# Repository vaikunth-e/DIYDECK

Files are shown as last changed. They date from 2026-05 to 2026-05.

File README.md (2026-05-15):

# DIYDECK: STM32 Audio Effects Processor with Custom PCB

DIYDECK is a custom audio-processing board/system that takes an external audio signal, conditions it for an STM32 ADC, applies real-time embedded DSP effects, and outputs the processed signal through the STM32 DAC into the audio board/amplifier path.

[Demo](https://youtu.be/CMMS7bL4tLE)

## Features

- STM32 Nucleo-F303RE firmware using PlatformIO
- Real-time ADC-to-DAC audio passthrough
- Timer-driven sampling using TIM3
- Freeverb-style reverb
- Ring modulation
- Rotary encoder control for PWM-selected filter settings
- Mute switch and button-controlled effects
- Custom KiCad PCB files included

## System overview

Input audio is AC-coupled and biased around mid-supply so the STM32 ADC can sample the waveform safely. The firmware removes the measured DC bias, applies optional effects, recenters the signal around the DAC midpoint, and outputs it through DAC channel 1.

Signal chain:

Laptop / audio source  
→ AC coupling and biasing  
→ STM32 ADC input  
→ real-time DSP  
→ STM32 DAC output  
→ PCB audio path / amplifier / speaker

## Hardware

- STM32 Nucleo-F303RE
- ADC input: A0 / PA0 / ADC1_IN1
- DAC output: A2 / PA4 / DAC_OUT1
- Rotary encoder for filter selection
- Effect buttons for reverb and ring modulation
- Mute switch
- Custom PCB designed in KiCad

## Firmware architecture

- `src/main.cpp`: ADC/DAC setup, audio ISR, effect toggles, timer setup
- `src/encoder_control.cpp`: rotary encoder decoding and PWM setting selection
- `lib/my_reverb`: Freeverb-style reverb implementation
- `lib/my_ringmod`: ring modulation effect

## Audio processing

Each sample is read from the ADC, denoised slightly by masking noisy LSBs, centered by subtracting a moving DC estimate, optionally processed through reverb and/or ring modulation, clipped to the DAC range, and written to the DAC.

## Filter / PWM control

The rotary encoder selects one of 16 predefined cutoff settings. Each setting maps a target cutoff frequency to two PWM duty cycles used by the external board.

## Debugging and validation

During bring-up, I debugged DC offset, clipping, low output volume, scratchiness, sample-rate instability, and ADC/DAC scaling. I used serial diagnostics and lab equipment including an oscilloscope, multimeter, function generator, and bench power supply to validate the signal path.

## Known limitations

- Audio quality depends heavily on input biasing and gain staging
- Some sample rates produced more noise or unstable effect behavior
- Reverb quality is constrained by STM32 memory and real-time processing budget

## Build and upload

```bash
pio run
pio run --target upload
pio device monitor

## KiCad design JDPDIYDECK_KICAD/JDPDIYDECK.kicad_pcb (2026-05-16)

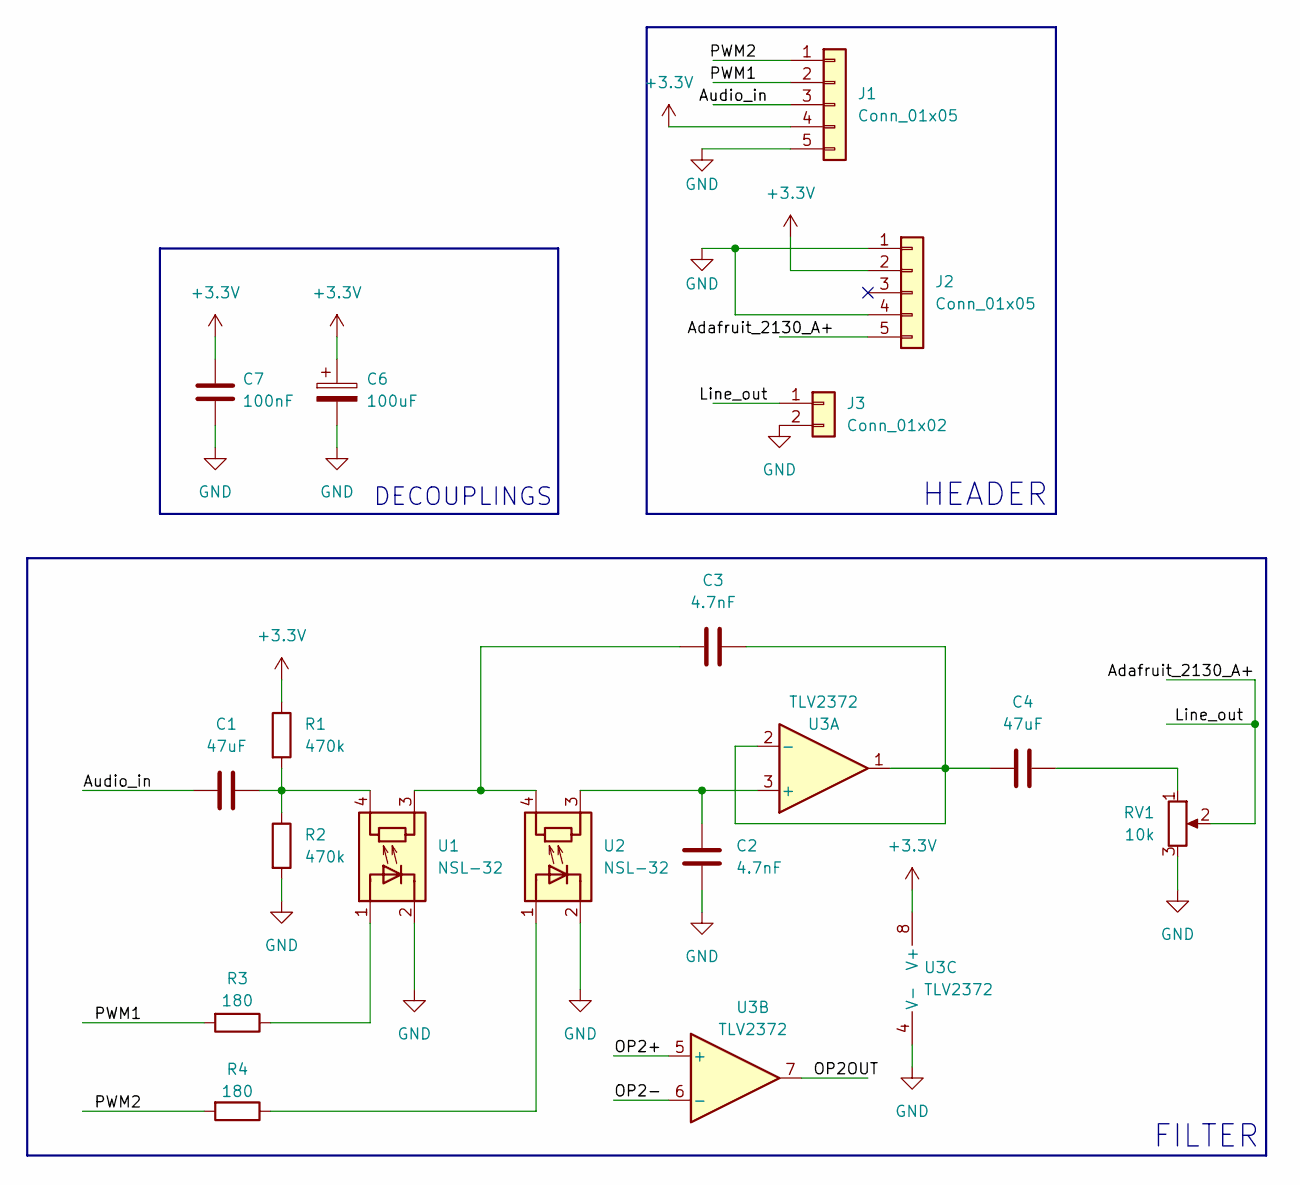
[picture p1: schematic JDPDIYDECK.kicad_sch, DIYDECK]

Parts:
C1, C4: 47uF; CAP_RDEC71E476MWK1H03B
C2, C3: 4.7nF; CAPRB500W50L400T250H550
C6: 100uF; CP_Radial_D5.0mm_P2.00mm
C7: 100nF; C_Rect_L4.0mm_W2.5mm_P2.50mm
J1: Conn_01x05; PinHeader_1x05_P2.54mm_Vertical
J2: Conn_01x05; PinSocket_1x05_P2.54mm_Vertical
J3: Conn_01x02; PinSocket_1x02_P2.54mm_Vertical
R1, R2: 470k; R_Axial_DIN0207_L6.3mm_D2.5mm_P10.16mm_Horizontal
R3, R4: 180; R_Axial_DIN0207_L6.3mm_D2.5mm_P10.16mm_Horizontal
RV1: 10k; Potentiometer_Bourns_PTV09A-1_Single_Vertical
U1, U2: NSL-32; Luna_NSL-32
U3: TLV2372; P8

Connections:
+3.3V: C6.1, C7.1, J1.4, J2.2, R1.1, U3.8 (V+)
/Adafruit_2130_A+: J2.5, J3.1, RV1.2
/Audio_in: C1.1, J1.3
/OP2+: U3.5 (+)
/OP2-: U3.6 (-)
/OP2OUT: U3.7
/PWM1: J1.2, R3.2
/PWM2: J1.1, R4.2
GND: C2.2, C6.2, C7.2, J1.5, J2.1, J2.4, J3.2, R2.2, RV1.3, U1.2 (K), U2.2 (K), U3.4 (V-)
unnamed: C1.2, R1.2, R2.1, U1.4 (R)
unnamed: C3.2, U1.3 (R), U2.4 (R)
unnamed: C4.2, RV1.1
unnamed: R3.1, U1.1 (A)
unnamed: R4.1, U2.1 (A)
unnamed: C2.1, U2.3 (R), U3.3 (+)
unnamed: C3.1, C4.1, U3.1, U3.2 (-)

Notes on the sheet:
HEADER
DECOUPLINGS
FILTER

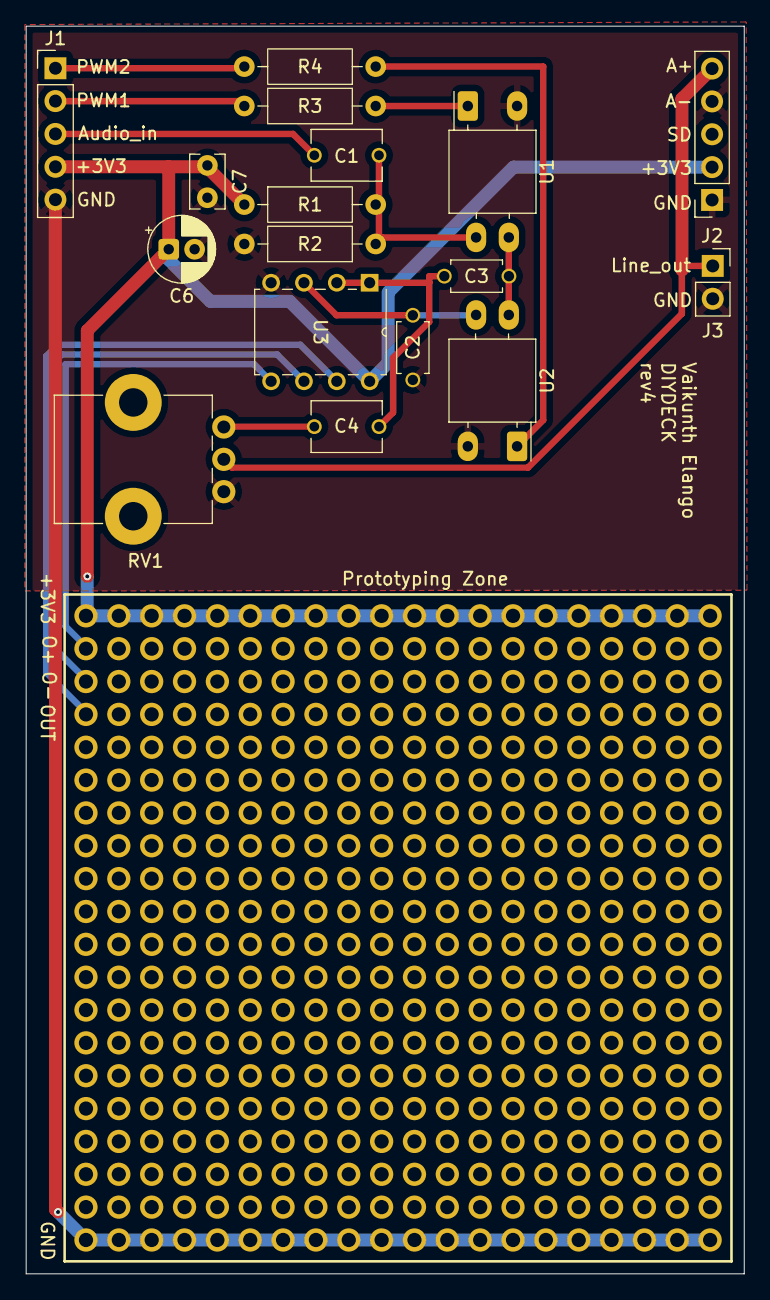
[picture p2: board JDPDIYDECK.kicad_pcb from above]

Board: 2 copper layers, 55.5 x 96.5 mm, 17 parts (0 on the bottom side), 13 nets.

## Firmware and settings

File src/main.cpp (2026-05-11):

#include <Arduino.h>
#include <HardwareTimer.h>
#include "stm32f3xx_hal.h" // stm32 functionality for ADC & DAC

#include "reverb_model.h" // reverb functionality
#include "ringmod.h" // ring modulation
#include "encoder_control.h" // rotary encoder

// Hardware mapping
// Input: A0 / PA0 = ADC1_IN1, Analog input
// Output: A2 / PA4 = DAC_OUT1, Analog output
// See circuit schematic for wiring and passive components
// Audio input should be AC-coupled and biased midpoint of supply voltage rabnge
// Audio output should be AC-coupled into the PCB's Audio_In input.

// Audio settings
// USing 32kHz, possible improvement? Sample rate of 16 kHz confirmed to provide decent audio; 8kHz is pretty noisy
// ADC uses 12-bit integer representation. Its integer range is thus 0 - 4095, and its voltage range is 0 - 3.3V, so 2048 is ~1.65V
// Biasing the AC audio to ADC midpoint is important because AC has negative voltages, while the ADC/DAC is unipolar and only handles 0 - 3.3V
static const uint32_t SAMPLE_RATE = 44100;
static const int ADC_MID = 2048;

// Increase gain to improve (NOT NECESSARY, old)
static const int GAIN_NUM = 1;
static const int GAIN_DEN = 1;

// audio effect pins
static const uint8_t REVERB_BUTTON = D4;
static const uint8_t RING_BUTTON = D2;
// rotary encoder pins
static const uint8_t ENCODER_CLK = D5;
static const uint8_t ENCODER_DT  = D6;
static const uint8_t ENCODER_SW  = D7;
// PWM output pins to board
static const uint8_t PWM1_PIN = D11;
static const uint8_t PWM2_PIN = D10;
// switch for audio mute
static const uint8_t MUTE_SWITCH_PIN = D8;

volatile bool reverbEnabled = false;
volatile bool ringEnabled = false;
volatile bool audioMuted = false;

volatile bool reverbPrintPending = false;
volatile bool reverbPrintState = false;
volatile bool ringPrintPending = false;
volatile bool ringPrintState = false;

static const float REVERB_WET = 0.45f;
static const float REVERB_DRY = 0.90f;
static const float REVERB_ROOMSIZE = 0.69f;
static const float REVERB_DAMPING = 0.20f;

// Ring modulation settings
static const float RING_CARRIER_HZ = 800.0f;
static const float RING_DRY = 0.70f;
static const float RING_WET = 0.60f;

static uint32_t ringPhase = 0;
static uint32_t ringPhaseInc = 0;

// Hardware timer enforces precise timing which is good for audio
// Timer/audio object's state
HardwareTimer *audioTimer = nullptr;

volatile uint32_t sampleCount = 0; // debug
volatile uint32_t clipLowCount = 0;
volatile uint32_t clipHighCount = 0;

volatile int dcEstimate = ADC_MID; // initial estimate of DC physical input bias, will be adjusted w/ MA depending on specific characteristics

// DAC: PA4 / DAC_OUT1
static inline void writeDAC(uint16_t value) {
  if (value > 4095) value = 4095;
  DAC1->DHR12R1 = value;
}

void setupDAC() {
  __HAL_RCC_GPIOA_CLK_ENABLE();
  __HAL_RCC_DAC1_CLK_ENABLE();

  // PA4 analog mode
  GPIOA->MODER |= GPIO_MODER_MODER4;
  GPIOA->PUPDR &= ~GPIO_PUPDR_PUPDR4;

  // Reset & enable DAC channel 1 (PA4)
  DAC1->CR = 0;
  DAC1->CR |= DAC_CR_EN1;

  // Midpoint output, 2048 is about 1.65 V (see above)
  writeDAC(2048);
}

// ADC: PA0 / ADC1_IN1
void setupADC() {
  __HAL_RCC_GPIOA_CLK_ENABLE();
  __HAL_RCC_ADC12_CLK_ENABLE();

  // PA0 analog mode, no pull-up/pull-down
  GPIOA->MODER |= GPIO_MODER_MODER0;
  GPIOA->PUPDR &= ~GPIO_PUPDR_PUPDR0;

  // Give ADC12 a synchronous clock from HCLK
  // This is important; calibration may never finish
  ADC12_COMMON->CCR &= ~ADC12_CCR_CKMODE;
  ADC12_COMMON->CCR |= ADC12_CCR_CKMODE_0;   // HCLK / 1

  // ADC is disabled before calibration/configuration.
  if (ADC1->CR & ADC_CR_ADEN) {
    ADC1->CR |= ADC_CR_ADDIS;
    while (ADC1->CR & ADC_CR_ADEN) {
      // wait
    }
  }

  // clear ADC ready flag
  ADC1->ISR |= ADC_ISR_ADRDY;

  // enable ADC's voltage regulator
  ADC1->CR &= ~ADC_CR_ADVREGEN;
  ADC1->CR |= ADC_CR_ADVREGEN_0;

  // delay for ADC's voltage regulator startup
  delay(10);

  // single ended calibration
  ADC1->CR &= ~ADC_CR_ADCALDIF;
  ADC1->CR |= ADC_CR_ADCAL;

  uint32_t t0 = millis();
  while (ADC1->CR & ADC_CR_ADCAL) {
    if (millis() - t0 > 1000) {
      Serial.println("FAILED: ADC calibration timeout"); // debug
      while (1) {}
    }
  }

  // Configure ADC:
  // 12 bit resolution, right aligned, single conversion, software trigger
  ADC1->CFGR = 0;

  // Long sample time for stability with bias network
  ADC1->SMPR1 &= ~ADC_SMPR1_SMP1;
  ADC1->SMPR1 |= ADC_SMPR1_SMP1;

  // Regular sequence length = 1 conversion
  ADC1->SQR1 = 0;

  // First conversion = channel 1, which is PA0 / ADC1_IN1
  ADC1->SQR1 |= (1U << ADC_SQR1_SQ1_Pos);

  // Enable ADC
  ADC1->CR |= ADC_CR_ADEN;

  t0 = millis();
  while (!(ADC1->ISR & ADC_ISR_ADRDY)) {
    if (millis() - t0 > 1000) {
      Serial.println("FAILED: ADC ready timeout"); // debug
      while (1) {}
    }
  }
}

static inline uint16_t readADC() {
  // Start one software conversion
  ADC1->CR |= ADC_CR_ADSTART;

  // Wait for conversion complete
  while (!(ADC1->ISR & ADC_ISR_EOC)) {
    // wait
  }

  return (uint16_t)(ADC1->DR & 0x0FFF);
}

// Audio ISR
// Direct ADC read + direct DAC write.
// at 16 kHz, this only has 62.5 us to complete work, so avoid slowdowns (Arduino r/w, Serial print)
void audioISR() {
  int sample = readADC();

  // Remove bottom two noisy bits
  sample = sample & ~0x03;

  // Slowly track actual DC bias
  dcEstimate = dcEstimate + ((sample - dcEstimate) >> 8); // moving average

  // Convert biased ADC sample into centered audio by removing estimated system DC bias
  // centers at 0
  int centered = sample - dcEstimate;

  // Optional gain
  centered = (centered * GAIN_NUM) / GAIN_DEN; // unnecessary

  // Shift back to DAC midpoint (ADC_MID = 2048 = 1.65V)
  // Reverb functionality added if reverb enabled
  int processed = centered;

  if (reverbEnabled) {
    processed = reverbProcessSample(processed);
  } 
  if (ringEnabled) {
    processed = ringModProcessSample(processed);
  }

  if (audioMuted) {
    processed = 0;
  } 
  
  int out = processed + ADC_MID;

  if (out < 0) {
    out = 0;
    clipLowCount++; // debug, check for too low
  }

  if (out > 4095) {
    out = 4095;
    clipHighCount++; // debug, check for too high
  }

  writeDAC((uint16_t)out); // write computed output to PCB Audio_In with the DAC

  sampleCount++; // debug
}

void reverbButtonISR() {
  static volatile uint32_t lastPressUs = 0;

  uint32_t now = micros();

  if ((uint32_t)(now - lastPressUs) > 250000UL) {
    reverbEnabled = !reverbEnabled;

    reverbPrintState = reverbEnabled;
    reverbPrintPending = true;

    lastPressUs = now;
  }
}

void ringButtonISR() {
  static volatile uint32_t lastPressUs = 0;

  uint32_t now = micros();

  if ((uint32_t)(now - lastPressUs) > 250000UL) {
    ringEnabled = !ringEnabled;

    ringPrintState = ringEnabled;
    ringPrintPending = true;

    lastPressUs = now;
  }
}

void setup() {
  Serial.setTx(PA2);
  Serial.setRx(PA3);

  Serial.begin(115200); // !!!!!!!!!!
  delay(1000); 

  Serial.println("Starting..."); // debug
  Serial.flush();

  setupADC();
  setupDAC();

  pinMode(REVERB_BUTTON, INPUT_PULLUP);
  attachInterrupt(digitalPinToInterrupt(REVERB_BUTTON), reverbButtonISR, FALLING);

  pinMode(RING_BUTTON, INPUT_PULLUP);
  attachInterrupt(digitalPinToInterrupt(RING_BUTTON), ringButtonISR, FALLING);

  pinMode(MUTE_SWITCH_PIN, INPUT_PULLUP);

  encoderControlInit(ENCODER_CLK, ENCODER_DT, ENCODER_SW, PWM1_PIN, PWM2_PIN); // the rotary encoder initialization

  // initialize reverb before enabling the audio interrupt
  reverbInit(SAMPLE_RATE);
  reverbSetWet(REVERB_WET);
  reverbSetDry(REVERB_DRY);
  reverbSetRoomSize(REVERB_ROOMSIZE);
  reverbSetDamping(REVERB_DAMPING);

  // initialize ring!
  ringModInit(SAMPLE_RATE);
  ringModSetCarrierHz(RING_CARRIER_HZ, SAMPLE_RATE);
  ringModSetMix(RING_DRY, RING_WET);

  audioTimer = new HardwareTimer(TIM3); // dont use TIM2
  audioTimer->setOverflow(SAMPLE_RATE, HERTZ_FORMAT);
  audioTimer->attachInterrupt(audioISR);
  audioTimer->resume();
}

void loop() {
  audioMuted = (digitalRead(MUTE_SWITCH_PIN) == LOW);

  encoderControlUpdate();
  if (encoderControlChanged()) {
    EncoderSetting s = encoderControlGetSetting();

    Serial.print("filter setting ");
    Serial.print(encoderControlGetIndex());

    Serial.print(" | cutoff ");
    Serial.print(s.cutoffHz);

    Serial.print(" hz | pwm1 ");
    Serial.print(s.pwm1Percent);

    Serial.print("% | pwm2 ");
    Serial.print(s.pwm2Percent);
    Serial.println("%");
  }

  if (reverbPrintPending) {
    noInterrupts();
    bool state = reverbPrintState;
    reverbPrintPending = false;
    interrupts();

    Serial.print("Reverb: ");
    Serial.println(state ? "ON" : "OFF");
  }

  if (ringPrintPending) {
    noInterrupts();
    bool state = ringPrintState;
    ringPrintPending = false;
    interrupts();

    Serial.print("Ring modulation: ");
    Serial.println(state ? "ON" : "OFF");
  }

  static uint32_t lastPrint = 0;

  if (millis() - lastPrint >= 1000) { // debug
    lastPrint = millis();

    noInterrupts();

    uint32_t samples = sampleCount;
    uint32_t clipsLow = clipLowCount; // debug
    uint32_t clipsHigh = clipHighCount;
    int dc = dcEstimate;

    sampleCount = 0; // debug
    clipLowCount = 0;
    clipHighCount = 0;

    interrupts();

    /*
    Serial.print("DC estimate: "); // debugg
    Serial.print(dc);

    Serial.print(" | samples/sec: ");
    Serial.print(samples);

    Serial.print(" | clip low: ");
    Serial.print(clipsLow);

    Serial.print(" | clip high: ");
    Serial.println(clipsHigh);
    */
  }
}

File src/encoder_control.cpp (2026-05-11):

#include "encoder_control.h"

namespace {

static uint8_t clkPin_;
static uint8_t dtPin_;
static uint8_t pwm1Pin_;
static uint8_t pwm2Pin_;

static uint8_t currentIndex = 0;
static bool changedFlag = false;

static bool lastClkState = HIGH;
static uint32_t lastStepMs = 0;

static const uint32_t STEP_DELAY_MS = 150;
static const uint32_t PWM_FREQ_HZ = 20000;

static const EncoderSetting settings[] = {
  {100.0f,       338628, 2,   3},
  {137.5979878f,246099, 2,   3},
  {189.3320626f,178854, 3,   4},
  {260.5171085f,129983, 3,   4},
  {358.4662992f,94466,  3,   4},
  {493.2424149f,68653,  5,   5},
  {678.6916381f,49894,  6,   6},
  {933.8660376f,36261,  7,   7},
  {1284.980877f,26353,  9,   9},
  {1768.107831f,19152,  12,  12},
  {2432.880798f,13919,  17,  17},
  {3347.595025f,10116,  23,  24},
  {4606.223396f,7352,   33,  36},
  {6338.070708f,5343,   47,  53},
  {8721.057762f,3883,   70,  80},
  {12000.0f,     2822,   100, 100}
};

static const uint8_t NUM_SETTINGS = sizeof(settings) / sizeof(settings[0]);

static uint8_t percentToPwm8(uint8_t percent) {
  if (percent >= 100) return 255;
  return (uint8_t)((percent * 255UL) / 100UL);
}

static void applyCurrentSetting() {
  const EncoderSetting &s = settings[currentIndex];

  analogWrite(pwm1Pin_, percentToPwm8(s.pwm1Percent));
  analogWrite(pwm2Pin_, percentToPwm8(s.pwm2Percent));

  changedFlag = true;
}

static void stepForward() {
  if (currentIndex < NUM_SETTINGS - 1) {
    currentIndex++;
  } else {
    currentIndex = 0;
  }

  applyCurrentSetting();
}

static void stepBackward() {
  if (currentIndex > 0) {
    currentIndex--;
  } else {
    currentIndex = NUM_SETTINGS - 1;
  }

  applyCurrentSetting();
}

} // namespace

void encoderControlInit(
    uint8_t clkPin,
    uint8_t dtPin,
    uint8_t swPin,
    uint8_t pwm1Pin,
    uint8_t pwm2Pin
) {
  (void)swPin;

  clkPin_ = clkPin;
  dtPin_ = dtPin;
  pwm1Pin_ = pwm1Pin;
  pwm2Pin_ = pwm2Pin;

  pinMode(clkPin_, INPUT_PULLUP);
  pinMode(dtPin_, INPUT_PULLUP);

  pinMode(pwm1Pin_, OUTPUT);
  pinMode(pwm2Pin_, OUTPUT);

  // 8 bit pwm makes analogWrite values 0 to 255
  analogWriteResolution(8);
  analogWriteFrequency(PWM_FREQ_HZ);

  currentIndex = 0;
  changedFlag = false;
  lastClkState = digitalRead(clkPin_);
  lastStepMs = millis();

  applyCurrentSetting();
}

void encoderControlUpdate() {
  bool clkState = digitalRead(clkPin_);
  bool dtState = digitalRead(dtPin_);
  uint32_t now = millis();

  // only react to a falling edge on clk
  if (lastClkState == HIGH && clkState == LOW) {
    // reject extra edges from bounce
    if (now - lastStepMs >= STEP_DELAY_MS) {
      lastStepMs = now;

      if (dtState == HIGH) {
        stepForward();
      } else {
        stepBackward();
      }
    }
  }

  lastClkState = clkState;
}

bool encoderControlChanged() {
  if (changedFlag) {
    changedFlag = false;
    return true;
  }

  return false;
}

uint8_t encoderControlGetIndex() {
  return currentIndex;
}

EncoderSetting encoderControlGetSetting() {
  return settings[currentIndex];
}

void encoderControlSetIndex(uint8_t index) {
  if (index >= NUM_SETTINGS) {
    index = NUM_SETTINGS - 1;
  }

  currentIndex = index;
  applyCurrentSetting();
}
